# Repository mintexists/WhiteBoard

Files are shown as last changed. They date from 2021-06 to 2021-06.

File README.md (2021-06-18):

# WhiteBoard

## A Budget-Oriented Ortholinear Keyboard

Current Version 1.1 - Adds support for pcb mount stabilizers, makes the design easier to assemble, and decreases price of production

Planned Improvements - Add support for an acrylic window for the components on the left

## Features
- Rotary Encoder
- Hot Swappable switches
- QMK and VIA support (Not upstream)
- Easy Assembly (Can be made entirely through hole)
- Budget Oriented
- Compatible with a variety of Microcontrollers

## Make Your Own

[Parts List](PartsList.md)

A Build Guide will be added shortly

## Images
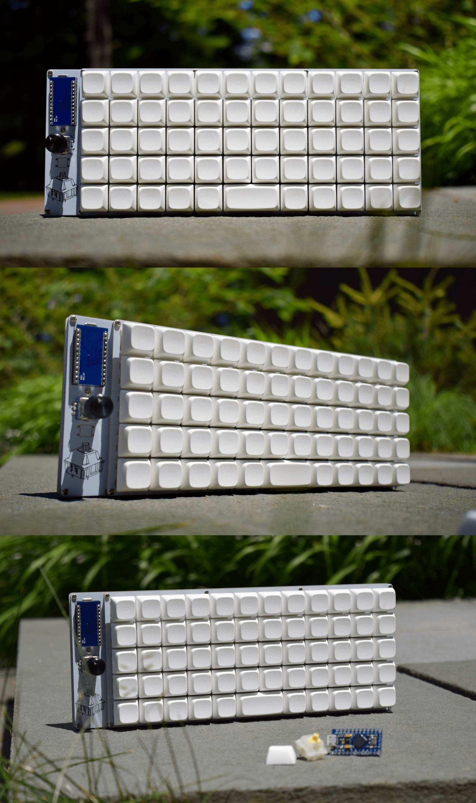
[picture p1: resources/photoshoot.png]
Keyboard


## My Keymap
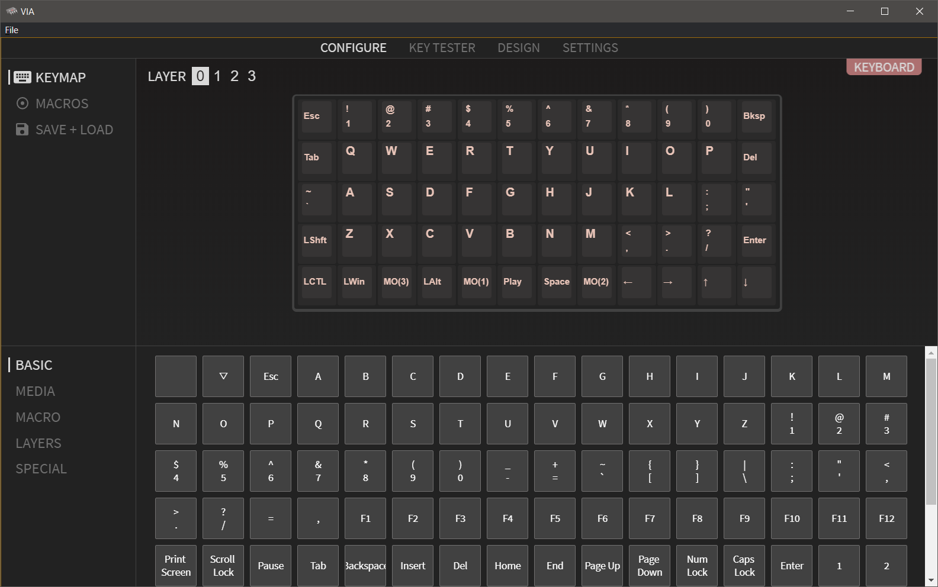
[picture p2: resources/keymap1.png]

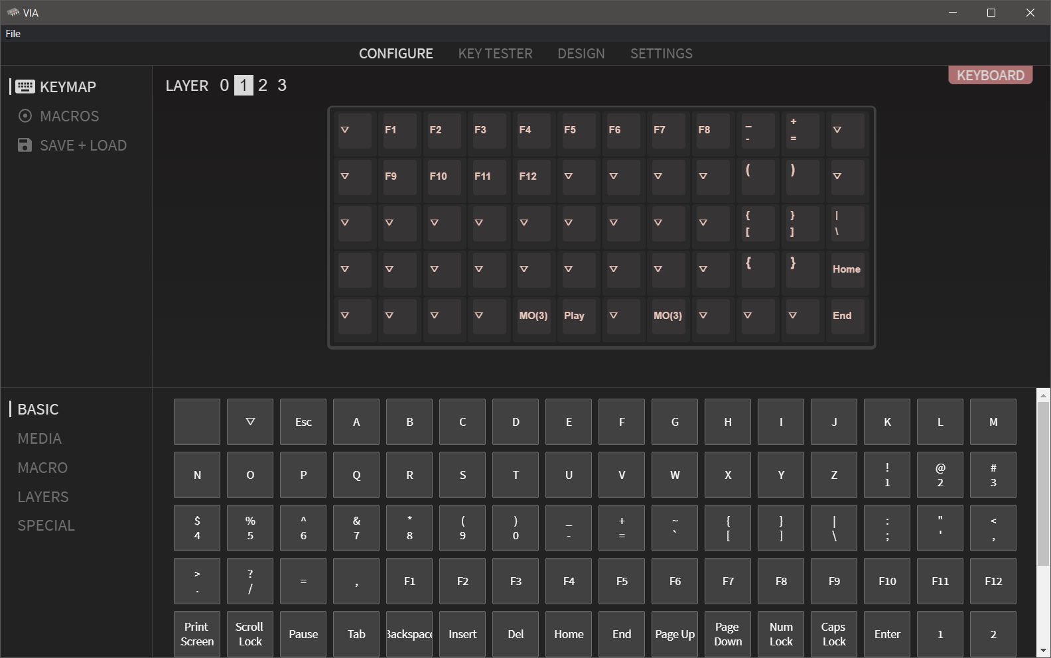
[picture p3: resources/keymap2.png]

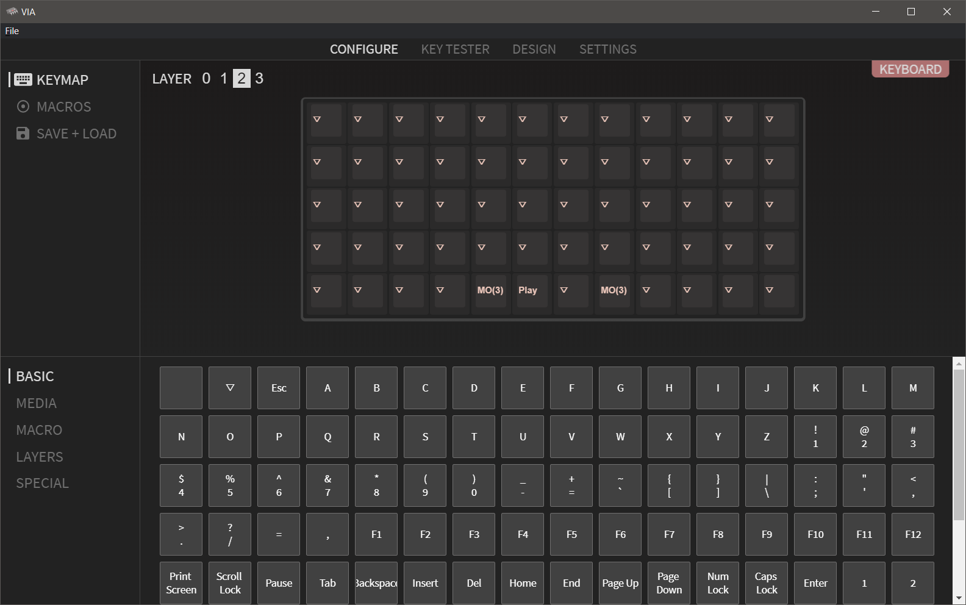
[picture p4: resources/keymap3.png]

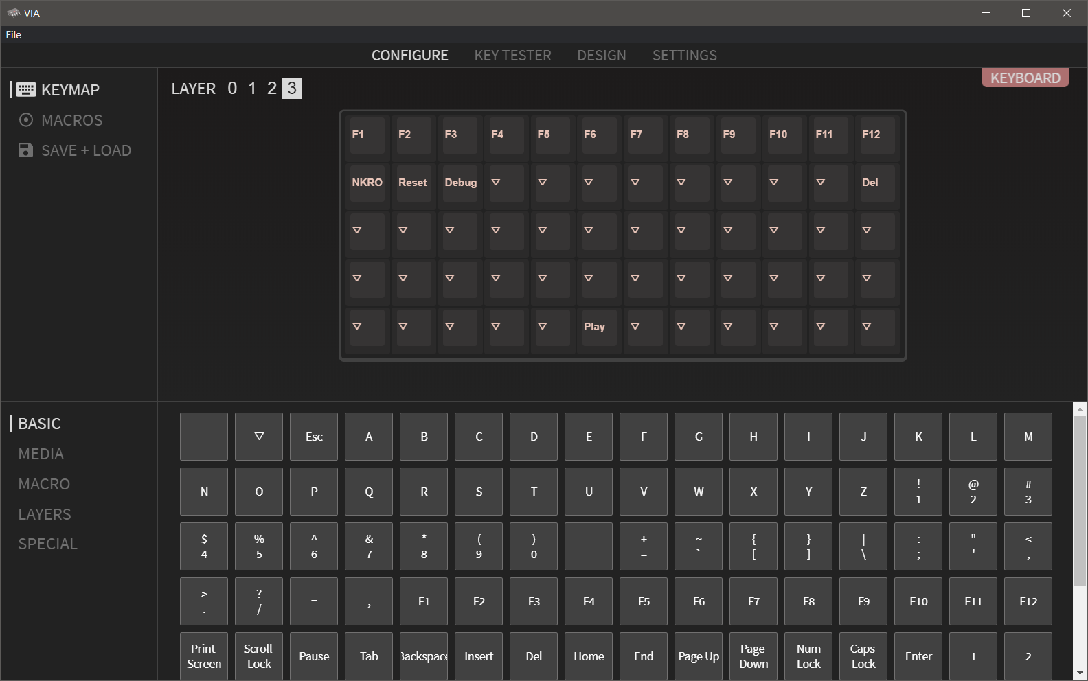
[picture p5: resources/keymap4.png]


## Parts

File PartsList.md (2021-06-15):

# Parts List

| Name | Count | Comment | Cost | Recommended |
|---|---|---|---|---|
| PCB | 1 | Many sites have minimum order quantities larger then 1 | $14.30 | JLCPCB |
| Plate | 1 | Many sites have minimum order quantities larger then 1 | $30.00 | JLCPCB |
| Bottom Plate | 1 | Many sites have minimum order quantities larger then 1 | $15.80 | JLCPCB |
| Pro Micro Compatible Microcontroller | 1 | I recommend the Elite-C by Keebio **Make sure you order a set with header pins if you are not using a socket** | $18 | https://keeb.io/products/elite-c-low-profile-version-usb-c-pro-micro-replacement-atmega32u4 |
| Diodes | 60 | Get more to be safe | $2.99 | https://keeb.io/products/1n4148-diodes |
| Hot Swap Sockets | 60 | Get more to be safe | $10 for 100 | https://kbdfans.com/products/mechanical-keyboard-switches-kailh-pcb-socket |
| M2 Screws | 100 | This is more then needed but good to be safe | | |
| M2 Standoffs | | Needs to be heights with a difference of 5mm, for example 5mm and 10mm or 3mm and 8mm<br>(Make sure the screws aren't too long in case of short standoffs) | | |
| Rotary Encoder | 1 | Make sure this is high quality as low quality encoders can have issues | $2 | https://keeb.io/products/rotary-encoder-ec11 |
| Encoder Knob | 1 | You can find cheaper knobs on Keebio but I prefer these | $15.99 | https://www.amazon.com/dp/B071DTQ2WN |
| Switches | 60 | | | |
| Keycaps | 60 | I recommend a set of uniform profile keycaps or a set of keycaps compatible with the Preonic | | |
| Plate Mount 2u Stabilizer | 1 | Currently this is not compatible with PCB mount stabilizers but this can be fixed if needed | | |
| (Optional) Microcontroller Sockets | 1 | Use these if you want the ability to change out what microcontroller you use | $4-$10 | |
| (Optional) 6mm Tactile Button | 1 | This is used as a reset button | | |
| (Optional) Braided USB Cable | 1 | Recommending Donut Cables here because they helped me out with learning some PCB design (I was not paid to say this) | $10-$20 | https://donutcables.com/ |

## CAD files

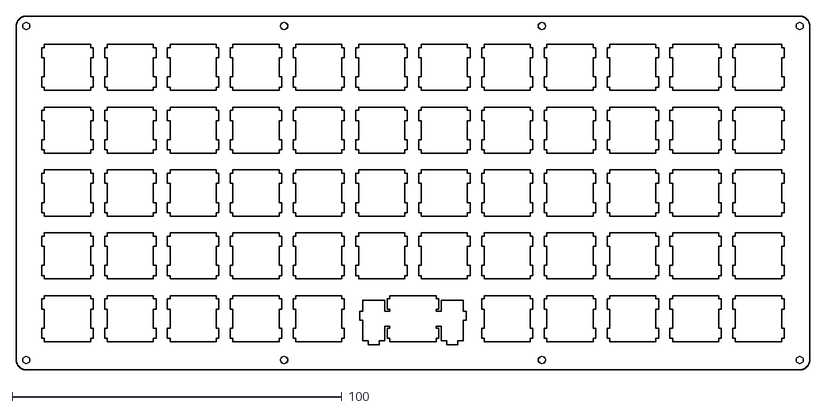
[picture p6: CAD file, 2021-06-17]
Kicad Files/Case cut files/67a69115050bf7e3c24235d57c8366504749e700_switch.dxf
240.6 x 107.3

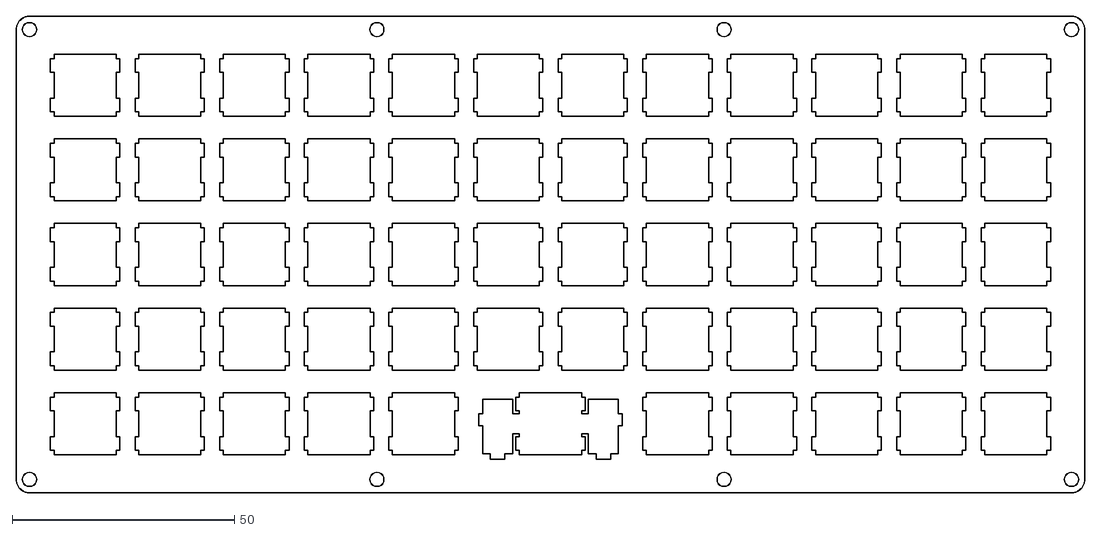
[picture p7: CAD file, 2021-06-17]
Kicad Files/Case cut files/eb55a980c9b8827bf49b83783b5de1276a03e77a_switch.dxf
240.6 x 107.3

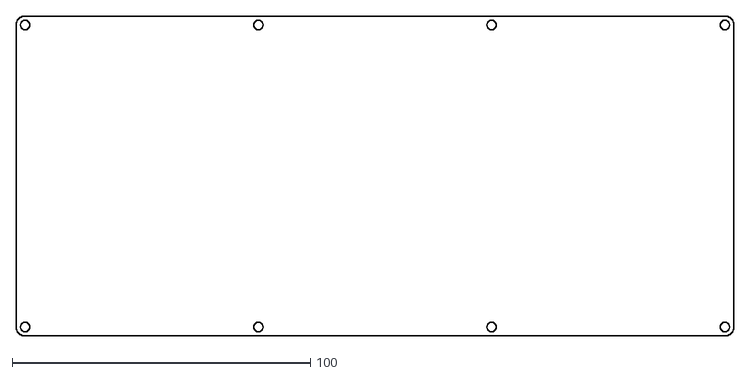
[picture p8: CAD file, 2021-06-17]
Kicad Files/Case cut files/eb55a980c9b8827bf49b83783b5de1276a03e77a_bottom.dxf
240.6 x 107.3

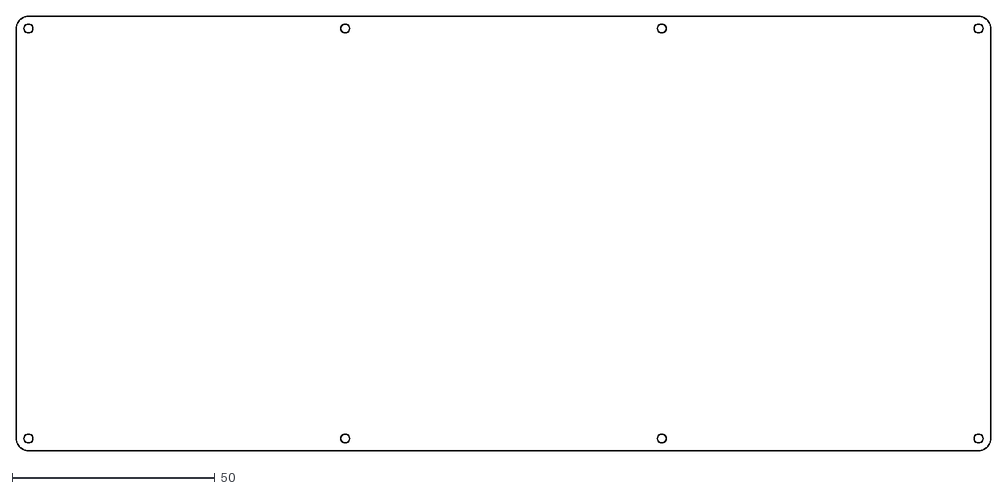
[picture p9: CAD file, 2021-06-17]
Kicad Files/Case cut files/67a69115050bf7e3c24235d57c8366504749e700_bottom.dxf
240.6 x 107.3

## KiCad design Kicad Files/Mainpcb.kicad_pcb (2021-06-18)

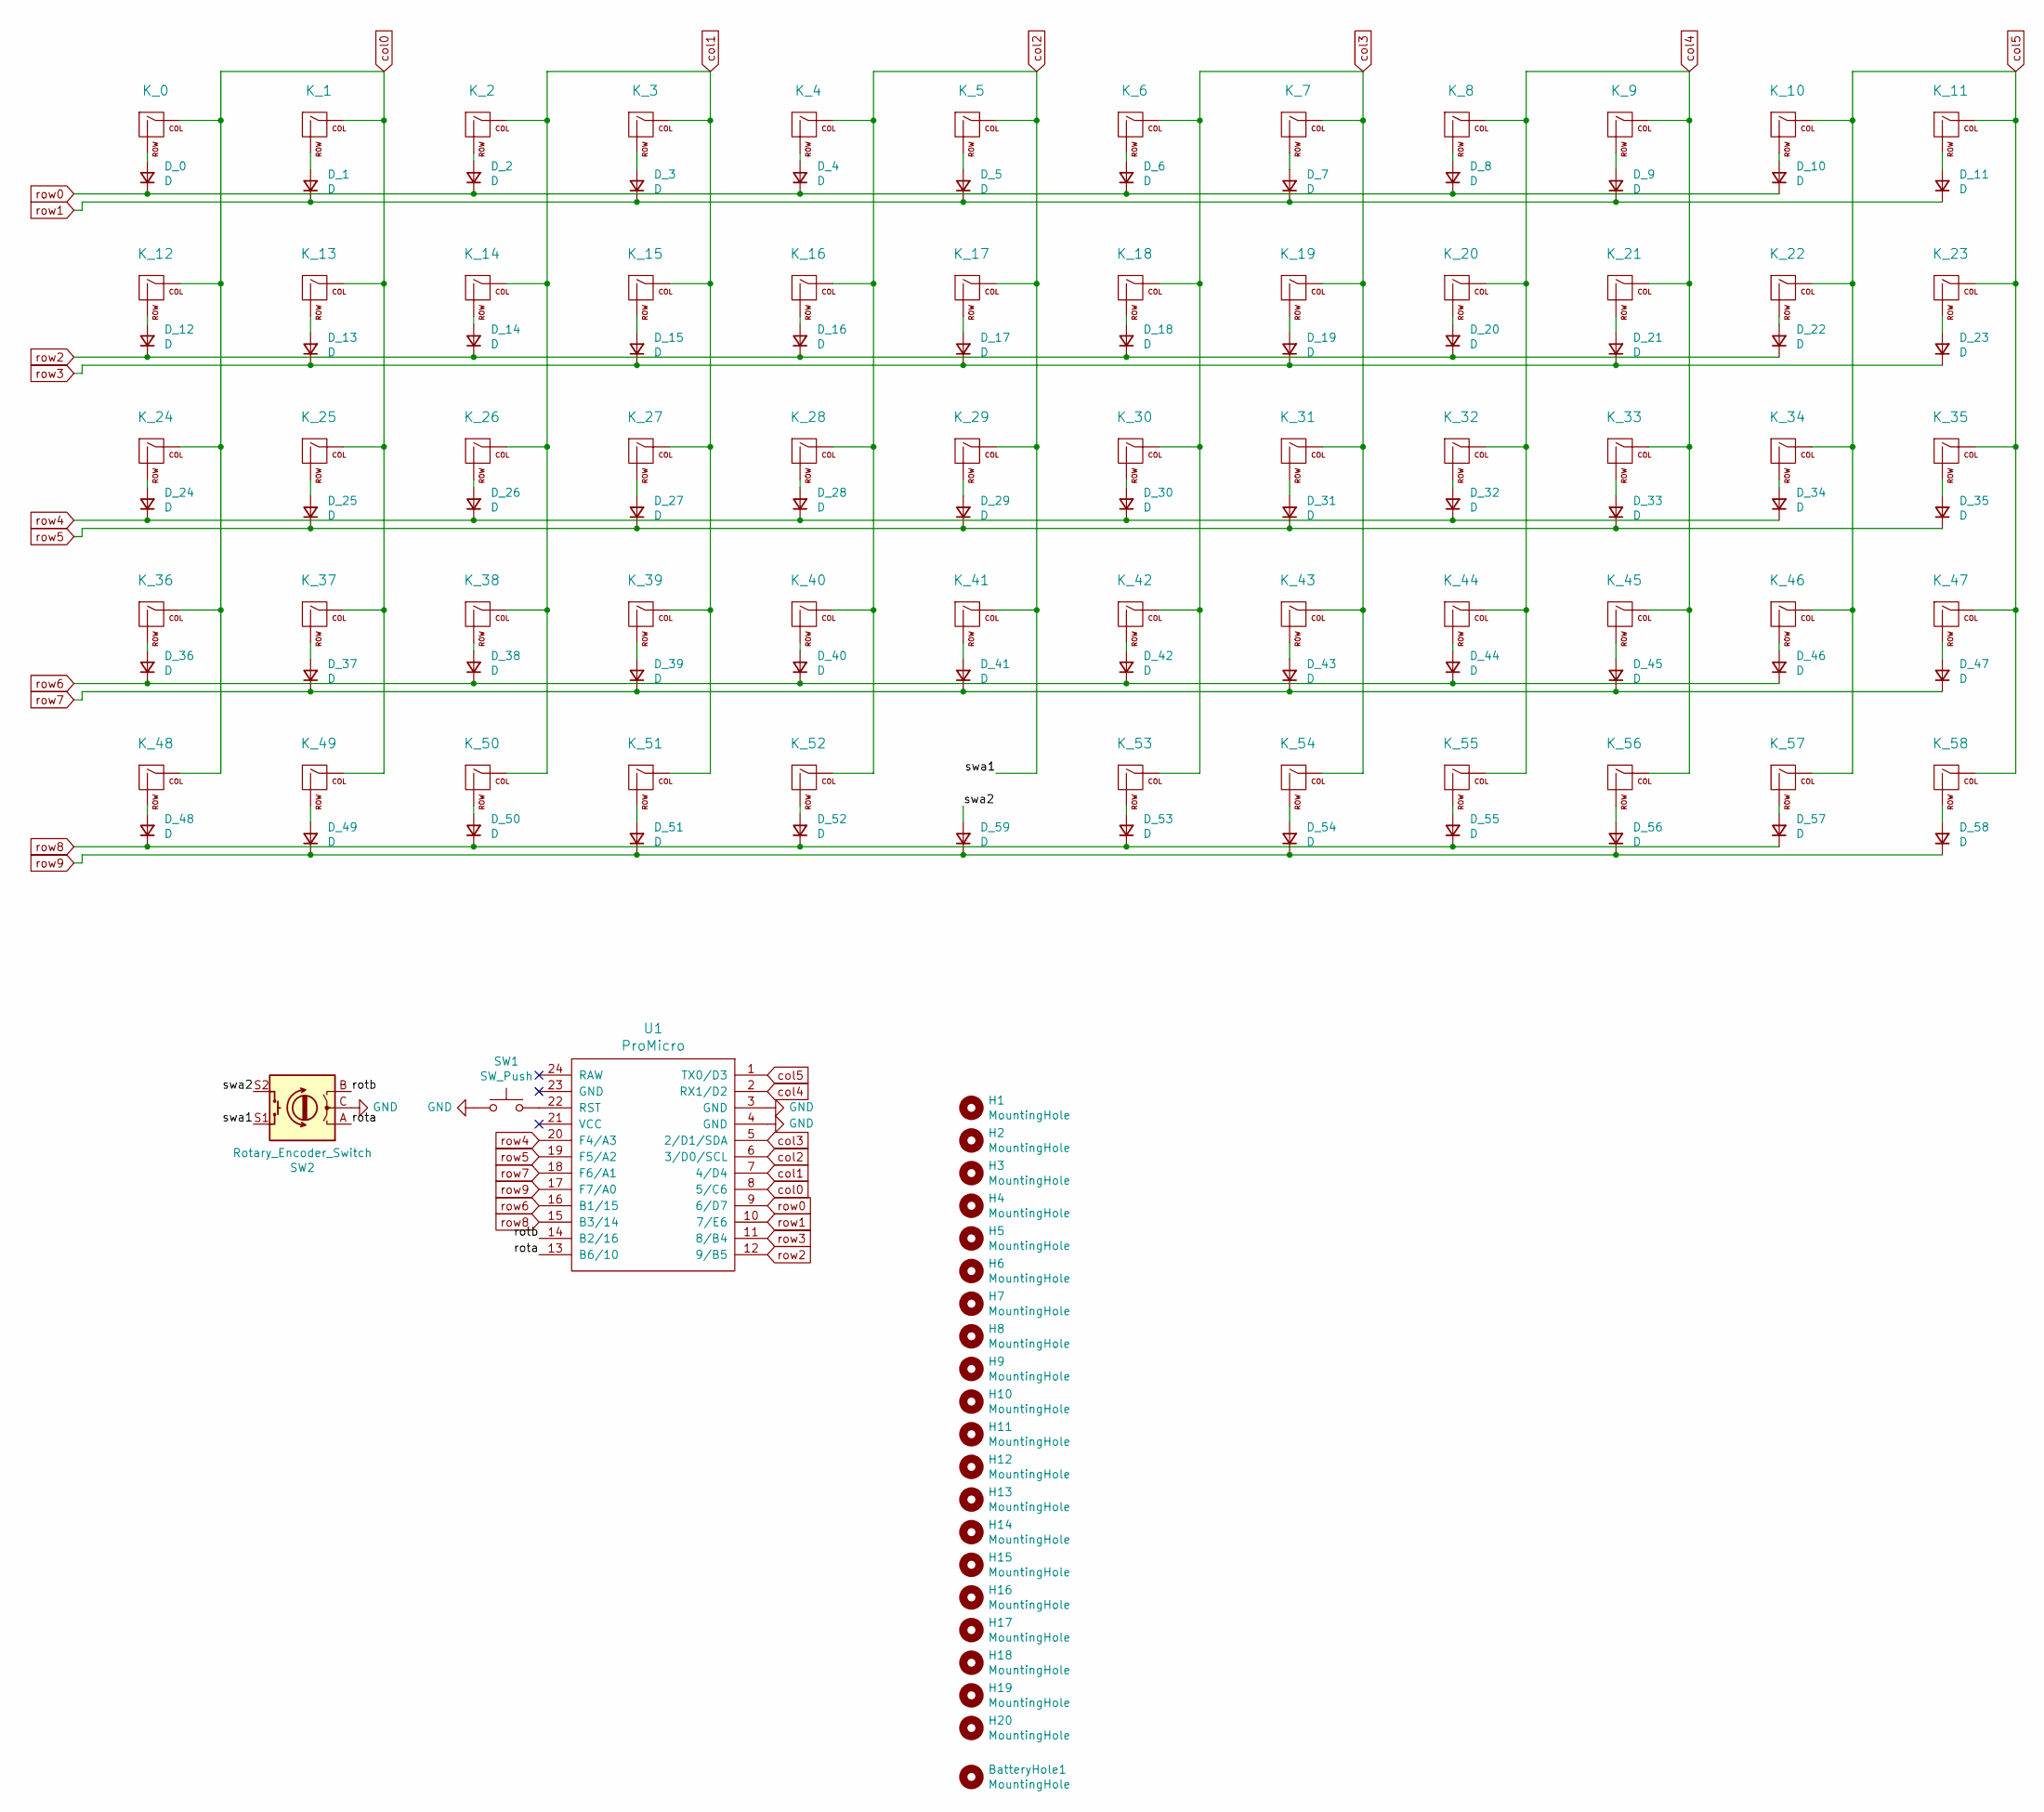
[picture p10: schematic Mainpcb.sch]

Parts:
BatteryHole1: MountingHole; MountingHole_5.3mm_M5
D_0, D_1, D_2, D_3, D_4, D_5, D_6, D_7, D_8, D_9, D_10, D_11, D_12, D_13, D_14, D_15, D_16, D_17, D_18, D_19, D_20, D_21, D_22, D_23, D_24, D_25, D_26, D_27, D_28, D_29, D_30, D_31, D_32, D_33, D_34, D_35, D_36, D_37, D_38, D_39, D_40, D_41, D_42, D_43, D_44, D_45, D_46, D_47, D_48, D_49, D_50, D_51, D_52, D_53, D_54, D_55, D_56, D_57, D_58, D_59: D; D_SOD123_axial
H1, H2, H3, H4, H5, H6, H7, H8, H9, H10: MountingHole; MountingHole_2.2mm_M2
H11, H12, H13, H14, H15, H16, H17, H18, H19, H20: MountingHole; MountingHole_3.5mm
K_0, K_1, K_2, K_3, K_4, K_5, K_6, K_7, K_8, K_9, K_10, K_11, K_12, K_13, K_14, K_15, K_16, K_17, K_18, K_19, K_20, K_21, K_22, K_23, K_24, K_25, K_26, K_27, K_28, K_29, K_30, K_31, K_32, K_33, K_34, K_35, K_36, K_37, K_38, K_39, K_40, K_41, K_42, K_43, K_44, K_45, K_46, K_47, K_48, K_49, K_50, K_51, K_52, K_53, K_54, K_55, K_56, K_57, K_58: KEYSW; Kailh_socket_MX
SW1: SW_Push; SW_Push_1P1T_NO_6x6mm_H9.5mm
SW2: Rotary_Encoder_Switch; RotaryEncoder_Alps_EC11E-Switch_Vertical_H20mm
U1: ProMicro; ArduinoProMicro-ZigZag

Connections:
/rota: SW2.A, U1.13 (B6/10)
/rotb: SW2.B, U1.14 (B2/16)
/swa2: D_59.2 (A), SW2.S2
GND: SW1.2, SW2.C, U1.3 (GND), U1.4 (GND)
unnamed: D_0.2 (A), K_0.2 (ROW)
unnamed: D_1.2 (A), K_1.2 (ROW)
unnamed: D_2.2 (A), K_2.2 (ROW)
unnamed: D_3.2 (A), K_3.2 (ROW)
unnamed: D_4.2 (A), K_4.2 (ROW)
unnamed: D_5.2 (A), K_5.2 (ROW)
unnamed: D_6.2 (A), K_6.2 (ROW)
unnamed: D_7.2 (A), K_7.2 (ROW)
unnamed: D_8.2 (A), K_8.2 (ROW)
unnamed: D_9.2 (A), K_9.2 (ROW)
unnamed: D_10.2 (A), K_10.2 (ROW)
unnamed: D_11.2 (A), K_11.2 (ROW)
unnamed: D_12.2 (A), K_12.2 (ROW)
unnamed: D_13.2 (A), K_13.2 (ROW)
unnamed: D_14.2 (A), K_14.2 (ROW)
unnamed: D_15.2 (A), K_15.2 (ROW)
unnamed: D_16.2 (A), K_16.2 (ROW)
unnamed: D_17.2 (A), K_17.2 (ROW)
unnamed: D_18.2 (A), K_18.2 (ROW)
unnamed: D_19.2 (A), K_19.2 (ROW)
unnamed: D_20.2 (A), K_20.2 (ROW)
unnamed: D_21.2 (A), K_21.2 (ROW)
unnamed: D_22.2 (A), K_22.2 (ROW)
unnamed: D_23.2 (A), K_23.2 (ROW)
unnamed: D_24.2 (A), K_24.2 (ROW)
unnamed: D_25.2 (A), K_25.2 (ROW)
unnamed: D_26.2 (A), K_26.2 (ROW)
unnamed: D_27.2 (A), K_27.2 (ROW)
unnamed: D_28.2 (A), K_28.2 (ROW)
unnamed: D_29.2 (A), K_29.2 (ROW)
unnamed: D_30.2 (A), K_30.2 (ROW)
unnamed: D_31.2 (A), K_31.2 (ROW)
unnamed: D_32.2 (A), K_32.2 (ROW)
unnamed: D_33.2 (A), K_33.2 (ROW)
unnamed: D_34.2 (A), K_34.2 (ROW)
unnamed: D_35.2 (A), K_35.2 (ROW)
unnamed: D_36.2 (A), K_36.2 (ROW)
unnamed: D_37.2 (A), K_37.2 (ROW)
unnamed: D_38.2 (A), K_38.2 (ROW)
unnamed: D_39.2 (A), K_39.2 (ROW)
unnamed: D_40.2 (A), K_40.2 (ROW)
unnamed: D_41.2 (A), K_41.2 (ROW)
unnamed: D_42.2 (A), K_42.2 (ROW)
unnamed: D_43.2 (A), K_43.2 (ROW)
unnamed: D_44.2 (A), K_44.2 (ROW)
unnamed: D_45.2 (A), K_45.2 (ROW)
unnamed: D_46.2 (A), K_46.2 (ROW)
unnamed: D_47.2 (A), K_47.2 (ROW)
unnamed: D_48.2 (A), K_48.2 (ROW)
unnamed: D_49.2 (A), K_49.2 (ROW)
unnamed: D_50.2 (A), K_50.2 (ROW)
unnamed: D_51.2 (A), K_51.2 (ROW)
unnamed: D_52.2 (A), K_52.2 (ROW)
unnamed: D_53.2 (A), K_53.2 (ROW)
unnamed: D_54.2 (A), K_54.2 (ROW)
unnamed: D_55.2 (A), K_55.2 (ROW)
unnamed: D_56.2 (A), K_56.2 (ROW)
unnamed: D_57.2 (A), K_57.2 (ROW)
unnamed: D_58.2 (A), K_58.2 (ROW)
unnamed: SW1.1, U1.22 (RST)
col0: K_0.1 (COL), K_1.1 (COL), K_12.1 (COL), K_13.1 (COL), K_24.1 (COL), K_25.1 (COL), K_36.1 (COL), K_37.1 (COL), K_48.1 (COL), K_49.1 (COL), U1.8 (5/C6)
col1: K_2.1 (COL), K_3.1 (COL), K_14.1 (COL), K_15.1 (COL), K_26.1 (COL), K_27.1 (COL), K_38.1 (COL), K_39.1 (COL), K_50.1 (COL), K_51.1 (COL), U1.7 (4/D4)
col2: K_4.1 (COL), K_5.1 (COL), K_16.1 (COL), K_17.1 (COL), K_28.1 (COL), K_29.1 (COL), K_40.1 (COL), K_41.1 (COL), K_52.1 (COL), SW2.S1, U1.6 (3/D0/SCL)
col3: K_6.1 (COL), K_7.1 (COL), K_18.1 (COL), K_19.1 (COL), K_30.1 (COL), K_31.1 (COL), K_42.1 (COL), K_43.1 (COL), K_53.1 (COL), K_54.1 (COL), U1.5 (2/D1/SDA)
col4: K_8.1 (COL), K_9.1 (COL), K_20.1 (COL), K_21.1 (COL), K_32.1 (COL), K_33.1 (COL), K_44.1 (COL), K_45.1 (COL), K_55.1 (COL), K_56.1 (COL), U1.2 (RX1/D2)
col5: K_10.1 (COL), K_11.1 (COL), K_22.1 (COL), K_23.1 (COL), K_34.1 (COL), K_35.1 (COL), K_46.1 (COL), K_47.1 (COL), K_57.1 (COL), K_58.1 (COL), U1.1 (TX0/D3)
row0: D_0.1 (K), D_2.1 (K), D_4.1 (K), D_6.1 (K), D_8.1 (K), D_10.1 (K), U1.9 (6/D7)
row1: D_1.1 (K), D_3.1 (K), D_5.1 (K), D_7.1 (K), D_9.1 (K), D_11.1 (K), U1.10 (7/E6)
row2: D_12.1 (K), D_14.1 (K), D_16.1 (K), D_18.1 (K), D_20.1 (K), D_22.1 (K), U1.12 (9/B5)
row3: D_13.1 (K), D_15.1 (K), D_17.1 (K), D_19.1 (K), D_21.1 (K), D_23.1 (K), U1.11 (8/B4)
row4: D_24.1 (K), D_26.1 (K), D_28.1 (K), D_30.1 (K), D_32.1 (K), D_34.1 (K), U1.20 (F4/A3)
row5: D_25.1 (K), D_27.1 (K), D_29.1 (K), D_31.1 (K), D_33.1 (K), D_35.1 (K), U1.19 (F5/A2)
row6: D_36.1 (K), D_38.1 (K), D_40.1 (K), D_42.1 (K), D_44.1 (K), D_46.1 (K), U1.16 (B1/15)
row7: D_37.1 (K), D_39.1 (K), D_41.1 (K), D_43.1 (K), D_45.1 (K), D_47.1 (K), U1.18 (F6/A1)
row8: D_48.1 (K), D_50.1 (K), D_52.1 (K), D_53.1 (K), D_55.1 (K), D_57.1 (K), U1.15 (B3/14)
row9: D_49.1 (K), D_51.1 (K), D_54.1 (K), D_56.1 (K), D_58.1 (K), D_59.1 (K), U1.17 (F7/A0)

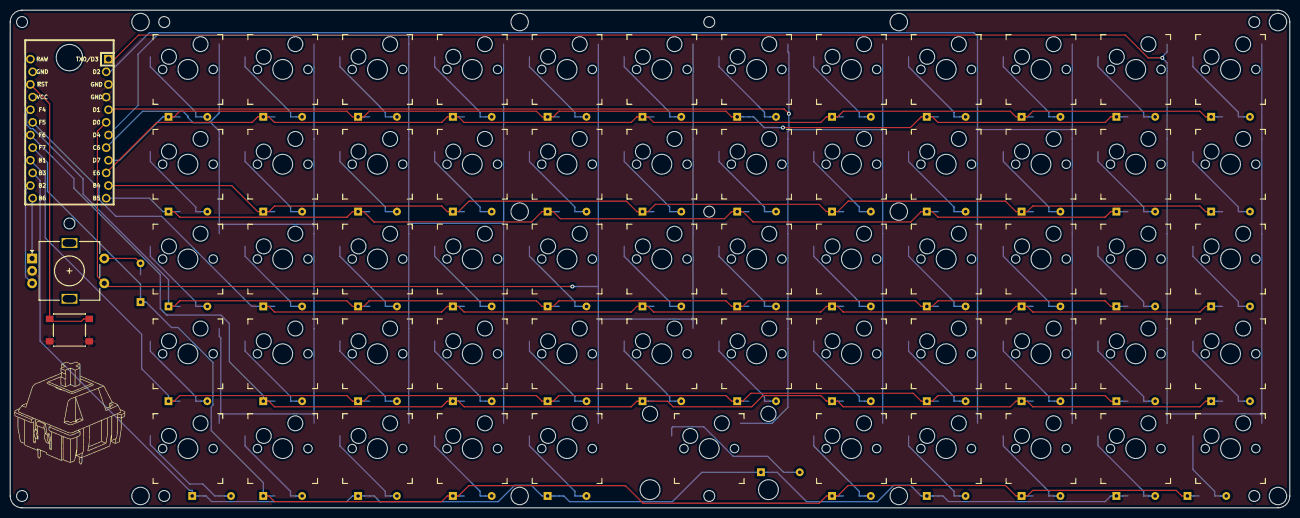
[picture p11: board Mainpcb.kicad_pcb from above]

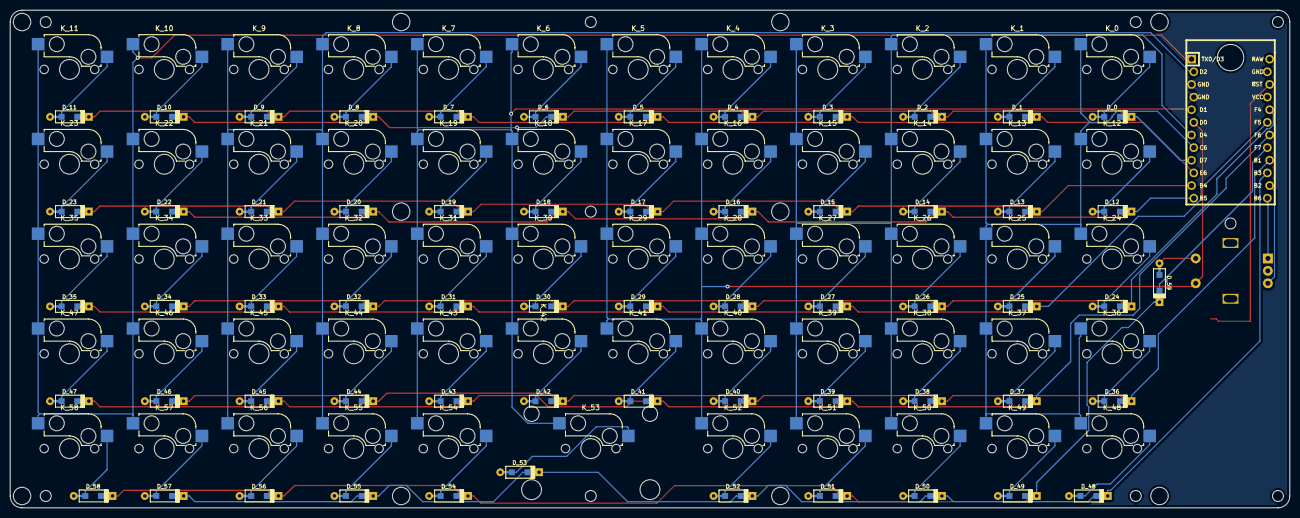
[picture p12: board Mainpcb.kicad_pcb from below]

Board: 2 copper layers, 257.2 x 100.0 mm, 143 parts (61 on the bottom side), 80 nets.

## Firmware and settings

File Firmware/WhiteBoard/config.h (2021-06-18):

#ifndef CONFIG_H
#define CONFIG_H

#include "config_common.h"  

/* USB Device descriptor parameter */
#define VENDOR_ID 0xDCAB
#define PRODUCT_ID 0x2001
#define DEVICE_VER      0x0001
#define MANUFACTURER    eva
#define PRODUCT         nya
#define DESCRIPTION     uwu

/* key matrix size */
#define MATRIX_ROWS 10
#define MATRIX_COLS 6

/* key matrix pins */
#define MATRIX_ROW_PINS { D7, E6, B5, B4, F4, F5, B1, F6, B3, F7 }
#define MATRIX_COL_PINS { C6, D4, D0, D1, D2, D3 }
#define UNUSED_PINS

#define ENCODERS_PAD_A { B2 }
#define ENCODERS_PAD_B { B6 }

#define DYNAMIC_KEYMAP_LAYER_COUNT 4

/* COL2ROW or ROW2COL */
#define DIODE_DIRECTION COL2ROW

/* number of backlight levels */

#ifdef BACKLIGHT_PIN
#define BACKLIGHT_LEVELS 3
#endif

/* Set 0 if debouncing isn't needed */
#define DEBOUNCING_DELAY 5

/* Mechanical locking support. Use KC_LCAP, KC_LNUM or KC_LSCR instead in keymap */
#define LOCKING_SUPPORT_ENABLE

/* Locking resynchronize hack */
#define LOCKING_RESYNC_ENABLE

/* key combination for command */
#define IS_COMMAND() ( \
    keyboard_report->mods == (MOD_BIT(KC_LSHIFT) | MOD_BIT(KC_RSHIFT)) \
)

/* prevent stuck modifiers */
#define PREVENT_STUCK_MODIFIERS


#ifdef RGB_DI_PIN
#define RGBLIGHT_ANIMATIONS
#define RGBLED_NUM 0
#define RGBLIGHT_HUE_STEP 8
#define RGBLIGHT_SAT_STEP 8
#define RGBLIGHT_VAL_STEP 8
#endif

#endif

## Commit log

2021-06-17 Upload kicad files
    [67a69115050bf7e3c24235d57c8366504749e700_bottom.dxf, 67a69115050bf7e3c24235d57c8366504749e700_switch.dxf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]
2021-06-18 Fix the kicad library locations
2021-06-18 Fixed files and imroved pcb design
    [Mainpcb.dsn, Mainpcb.kicad_pcb, bottom.kicad_pcb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]
2021-06-18 Small change
    [Mainpcb.kicad_pcb]
2021-06-18 Add Gerbers
    [Mainpcb-B_Cu.gbr, Mainpcb-B_Mask.gbr, Mainpcb-B_Paste.gbr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]
